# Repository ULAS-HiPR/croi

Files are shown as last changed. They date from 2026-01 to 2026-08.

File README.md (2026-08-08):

# Croí

Croí is the core flight-computer node in [Ogma](https://sean-osullivan.com/projects/ogma/), the University of Limerick Aeronautics Society's modular avionics stack for high-powered rocketry.

## Role

- Coordinates flight state across the 500 kbit/s CAN bus.
- Samples an LSM6DSO32 IMU and MS5607 barometer.
- Records flight data to SPI NOR flash.
- Runs on an STM32F072 and can operate as the stack's central logger.

## Repository

- `hardware/` - KiCad design and manufacturing outputs.
- `firmware/` - embedded firmware, peripheral probes, and tests.
- `schematics.png` - exported schematic overview.

## Status

Rev 1 firmware and hardware bring-up continue on [`ogma/flight-hardening`](https://github.com/ULAS-HiPR/croi/tree/ogma/flight-hardening). Release-candidate firmware builds and software tests pass, but hardware-in-the-loop validation is still underway. Croí is not yet flight-proven.

## Manufacturing support

Rev 1 PCB fabrication was sponsored through [EasyEDA Education](https://easyeda.com/education) and manufactured by [JLCPCB](https://jlcpcb.com/). The board was designed in KiCad and imported into EasyEDA Pro for the sponsorship and manufacturing workflow.

## More information

See the [Ogma project write-up](https://sean-osullivan.com/projects/ogma/) for the complete stack, bring-up work, and current status.

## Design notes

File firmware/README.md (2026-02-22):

# Croi

Heart of flight computer. It will run the Kalman filter and flight state machine. It is the core board to determine and send the trigger to the pyro board for  parachutes.

# Set-Up

```bash
git clone git@github.com:ULAS-HiPR/croi.git
cd croi
git submodule update --init --recursive
```

# Libraries used:

## From Braiteoiri:

- Flash: W25N01GV
- Baro: BMP390
- IMU:  LSM6DSO32
- Env: BME680
- LED
- Buzzer

## From Comheadan:

- CAN
- SPI
- I2C

## Other:
- FreeRTOS -> Cmsis wrapper, copied from gnereateed code from STM32CubeIDE
- Eigen

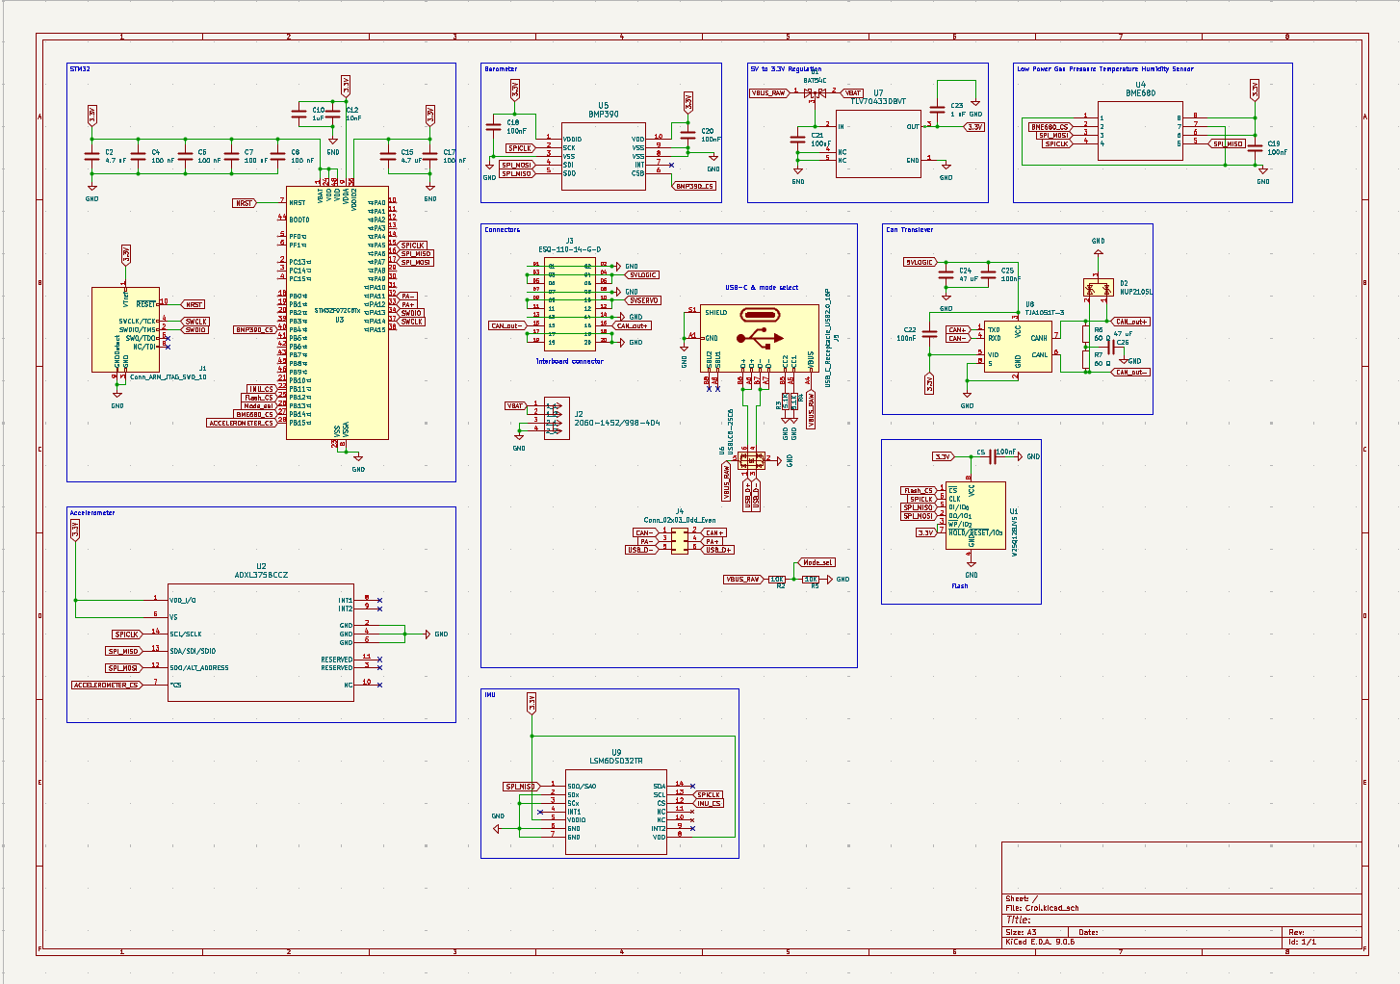
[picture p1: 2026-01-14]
schematics.png

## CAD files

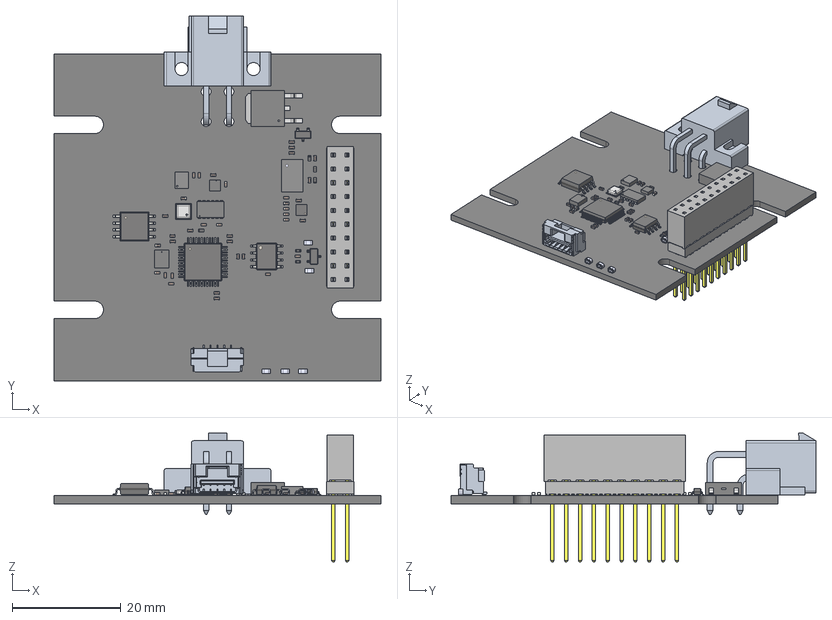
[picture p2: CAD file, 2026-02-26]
hardware/Croí - Kicad/Croí.step
60.0 x 66.9 x 23.6 mm
C_0402_1005Metric x 36
LGA_CC-14-1_ADI
PG-TO252-3-313_INF
R_0402_1005Metric x 6
S2761-46R x 5
XTAL_NX3225GD-8MHZ-STD-CRA-3_NDK
10LGA_2X2X0p75_BOS
SOIC-8_3.9x4.9mm_P1.27mm
SOIC-8_5.3x5.3mm_P1.27mm
ESQ-110-14-G-D-LL_socket
ESQ-110-14-G-D-LL_pins
ESQ-110-14-G-D-LL2_pins
ESQ-110-14-G-D-LL_bpins
LQFP-48_7x7mm_P0.5mm
MPM3650CGQW
LSM6DSO32TR 3D Model STEP
SOT-23 x 2
BME680 3D Model STEP 510211
WSON-6-1EP_2x2mm_P0.65mm_EP1x1.6mm
CroÃ_PCB

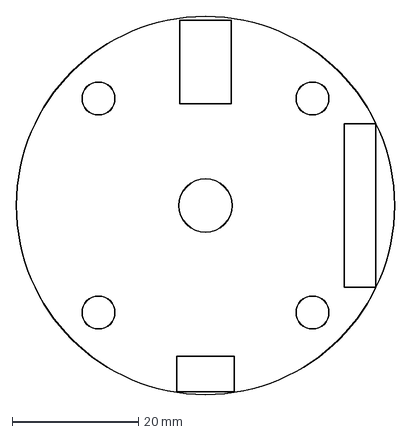
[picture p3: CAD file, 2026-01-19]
hardware/standardFootprint.dxf
60.0 x 60.0 mm

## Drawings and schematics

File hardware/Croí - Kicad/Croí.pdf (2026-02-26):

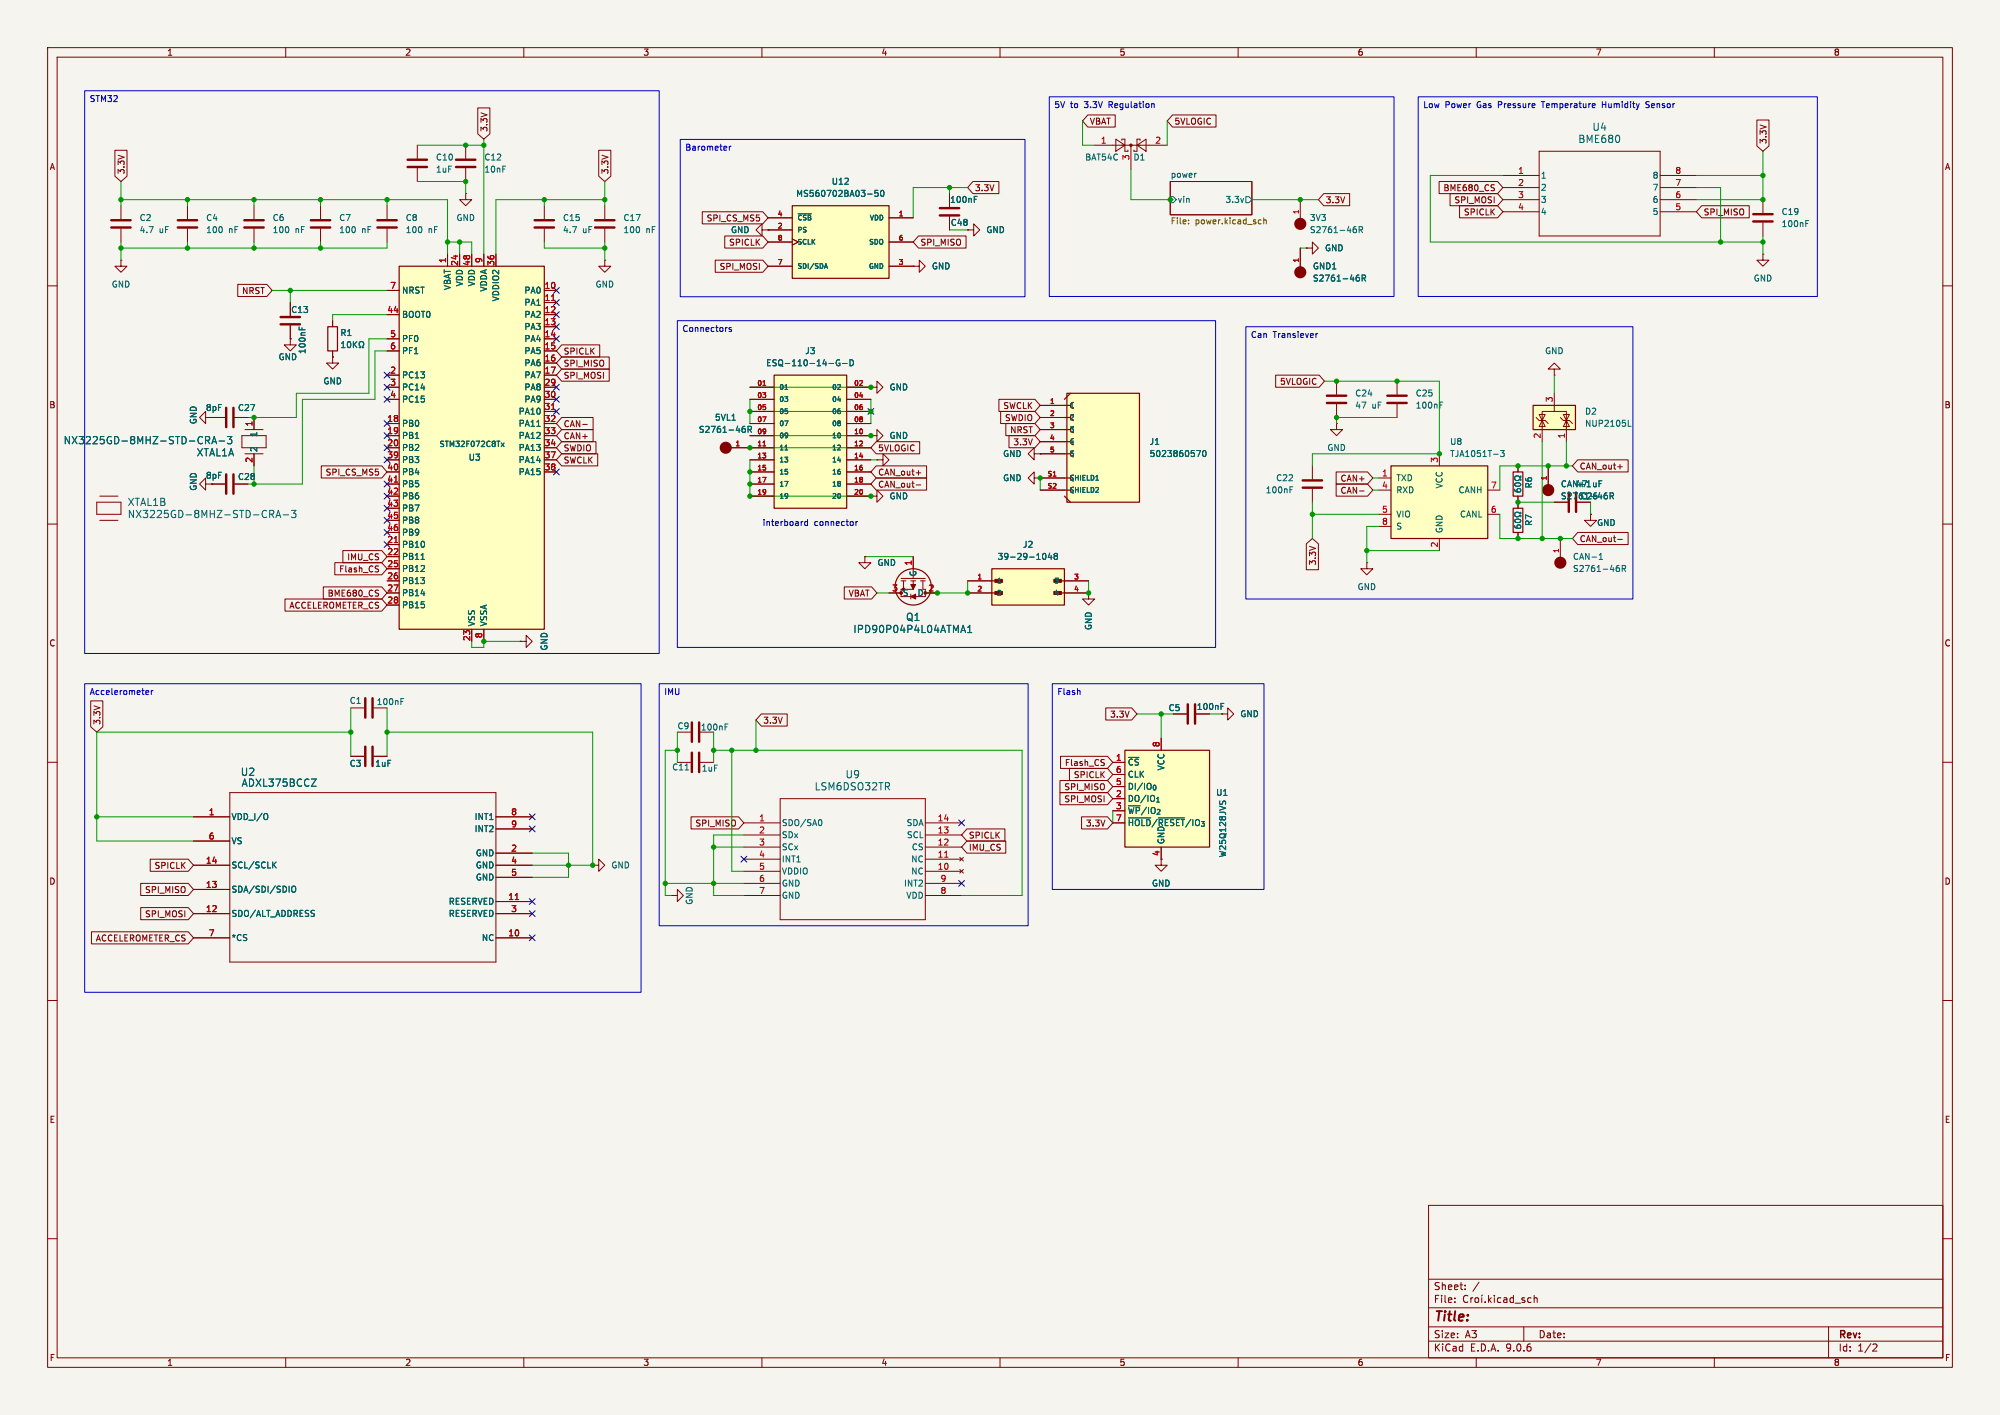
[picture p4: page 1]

1 VDD 24 VDD 48 VSS 23 VDDA

4 U1W25Q128JVS C5 100nF GND GND GND GND

Id: 1/2 Title: File: þÿCroí.kicad_sch Sheet: /

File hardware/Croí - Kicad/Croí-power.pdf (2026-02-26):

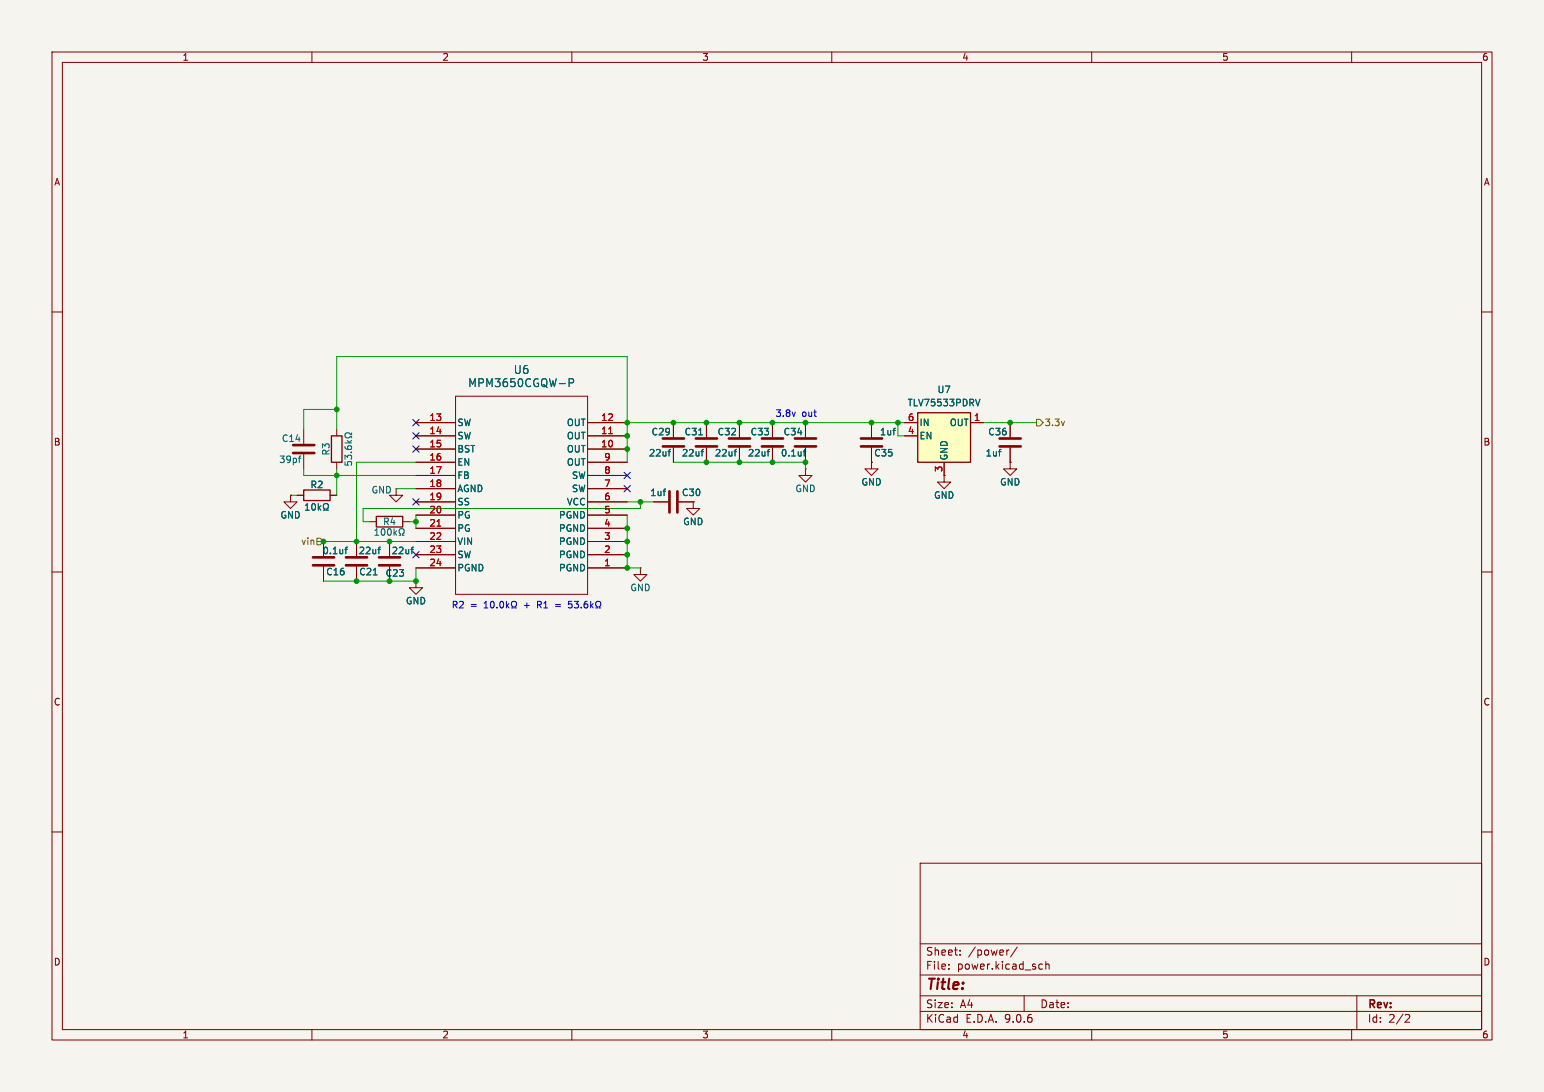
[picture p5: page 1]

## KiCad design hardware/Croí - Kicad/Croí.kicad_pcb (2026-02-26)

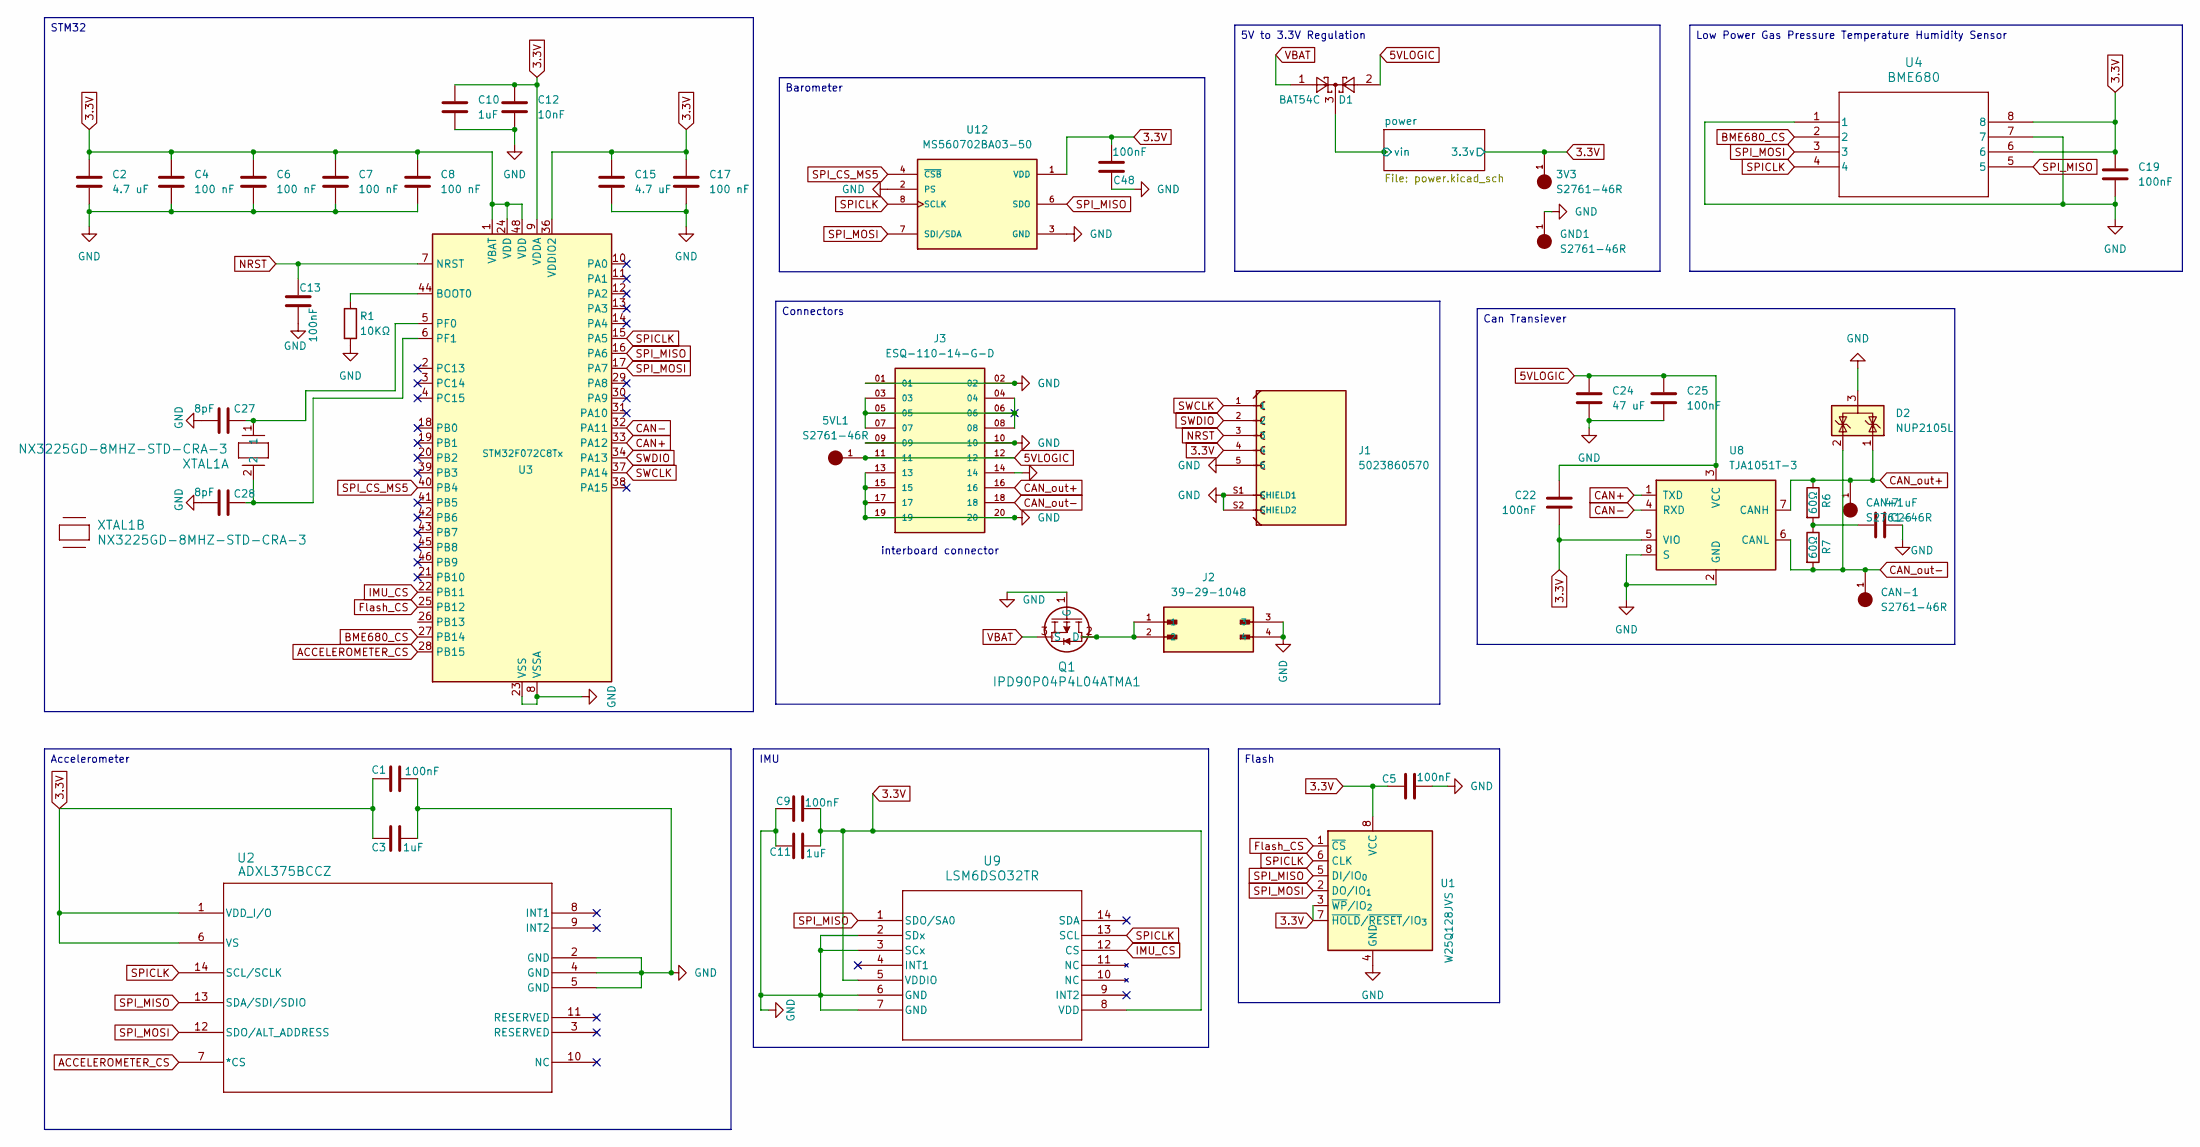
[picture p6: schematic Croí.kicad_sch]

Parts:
3V3, 5VL1: S2761-46R; HARWIN_S2761-46R; PARTREV 1
C1, C5, C9, C13, C19, C22, C25: 100nF; C_0402_1005Metric
C2, C15: 4.7 uF; C_0402_1005Metric
C3, C10, C11: 1uF; C_0402_1005Metric
C4, C6, C7, C8, C17: 100 nF; C_0402_1005Metric
C12: 10nF; C_0402_1005Metric
C24, C26: 47 uF; C_0402_1005Metric
C27, C28: 8pF; C_0402_1005Metric
C48: 100nF; R_0402_1005Metric
CAN+1: S2761-46R; HARWIN_S2761-46R; PARTREV 1
CAN-1: S2761-46R; HARWIN_S2761-46R; PARTREV 1
D1: BAT54C; SOT-23
D2: NUP2105L; SOT-23
GND1: S2761-46R; HARWIN_S2761-46R; PARTREV 1
J1: 5023860570; MOLEX_5023860570; PARTREV F
J2: 39-29-1048; MOLEX_39-29-1048
J3: ESQ-110-14-G-D; SAMTEC_ESQ-110-14-G-D; PARTREV NA
Q1: IPD90P04P4L04ATMA1; PG-TO252-3-313_INF
R1: 10KΩ; R_0402_1005Metric
R6, R7: 60Ω; R_0402_1005Metric
U1: W25Q128JVS; SOIC-8_5.3x5.3mm_P1.27mm
U2: ADXL375BCCZ; LGA_CC-14-1_ADI
U3: STM32F072C8Tx; LQFP-48_7x7mm_P0.5mm
U4: BME680; LGA8_BME680_BOS
U8: TJA1051T-3; SOIC-8_3.9x4.9mm_P1.27mm
U9: LSM6DSO32TR; LGA-14L_2P5X3X0P83_STM
U12: MS560702BA03-50; SON125P300X500X100-8N
XTAL1: NX3225GD-8MHZ-STD-CRA-3; XTAL_NX3225GD-8MHZ-STD-CRA-3_NDK

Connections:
3.3V: 3V3.1, C1.1, C2.1, C3.1, C4.1, C5.1, C6.1, C7.1, C8.1, C9.2, C10.1, C11.2, C12.1, C15.1, C17.1, C19.1, C22.1, C48.2, J1.4, U1.3 (~WP/IO_{2}), U1.7 (~HOLD/~RESET/IO_{3}), U1.8 (VCC), U2.1 (VDD_I/O), U2.6 (VS), U3.1 (VBAT), U3.9 (VDDA), U3.24 (VDD), U3.36 (VDDIO2), U3.48 (VDD), U4.6, U4.8, U8.5 (VIO), U9.5 (VDDIO), U9.8 (VDD), U12.1 (VDD); also elsewhere on the board
5VLOGIC: 5VL1.1, C22.2, C24.1, C25.1, D1.2, J3.11, J3.12, U8.3 (VCC)
/power/vin: D1.3; also elsewhere on the board
ACCELEROMETER_CS: U2.7 (*CS), U3.28 (PB15)
BME680_CS: U3.27 (PB14), U4.2
CAN+: U3.33 (PA12), U8.1 (TXD)
CAN-: U3.32 (PA11), U8.4 (RXD)
CAN_out+: CAN+1.1, D2.1 (K), J3.16, R6.1, U8.7 (CANH)
CAN_out-: CAN-1.1, D2.2 (K), J3.18, R7.2, U8.6 (CANL)
Flash_CS: U1.1 (~CS), U3.25 (PB12)
GND: C1.2, C2.2, C3.2, C4.2, C5.2, C6.2, C7.2, C8.2, C9.1, C10.2, C11.1, C12.2, C13.2, C15.2, C17.2, C19.2, C24.2, C25.2, C26.2, C27.1, C28.2, C48.1, D2.3 (A), GND1.1, J1.5, J1.S1 (SHIELD1), J1.S2 (SHIELD2), J2.3, J2.4, J3.01, J3.02, J3.09, J3.10, J3.13, J3.14, J3.15, J3.17, J3.19, J3.20, Q1.1 (G), R1.2, U1.4 (GND), U2.2 (GND), U2.4 (GND), U2.5 (GND), U3.8 (VSSA), U3.23 (VSS), U3.35 (VSS), U3.47 (VSS), U4.1, U4.7, U8.2 (GND), U8.8 (S), U9.2 (SDx), U9.3 (SCx), U9.6 (GND), U9.7 (GND), U12.2 (PS), U12.3 (GND); also elsewhere on the board
IMU_CS: U3.22 (PB11), U9.12 (CS)
NRST: C13.1, J1.3, U3.7 (NRST)
unnamed: C26.1, R6.2, R7.1
unnamed: J2.1, J2.2, Q1.2 (D)
unnamed: R1.1, U3.44 (BOOT0)
unnamed: C27.2, U3.5 (PF0), XTAL1.1
unnamed: C28.1, U3.6 (PF1), XTAL1.2
SPICLK: U1.6 (CLK), U2.14 (SCL/SCLK), U3.15 (PA5), U4.4, U9.13 (SCL), U12.8 (SCLK)
SPI_CS_MS5: U3.40 (PB4), U12.4 (~CSB), U12.5 (~CSB)
SPI_MISO: U1.5 (DI/IO_{0}), U2.13 (SDA/SDI/SDIO), U3.16 (PA6), U4.5, U9.1 (SDO/SA0), U12.6 (SDO)
SPI_MOSI: U1.2 (DO/IO_{1}), U2.12 (SDO/ALT_ADDRESS), U3.17 (PA7), U4.3, U12.7 (SDI/SDA)
SWCLK: J1.1, U3.37 (PA14)
SWDIO: J1.2, U3.34 (PA13)
VBAT: D1.1, Q1.3 (S)

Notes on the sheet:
interboard connector
Low Power Gas Pressure Temperature Humidity Sensor
Can Transiever
Barometer
Flash
5V to 3.3V Regulation
Accelerometer
IMU
STM32
Connectors

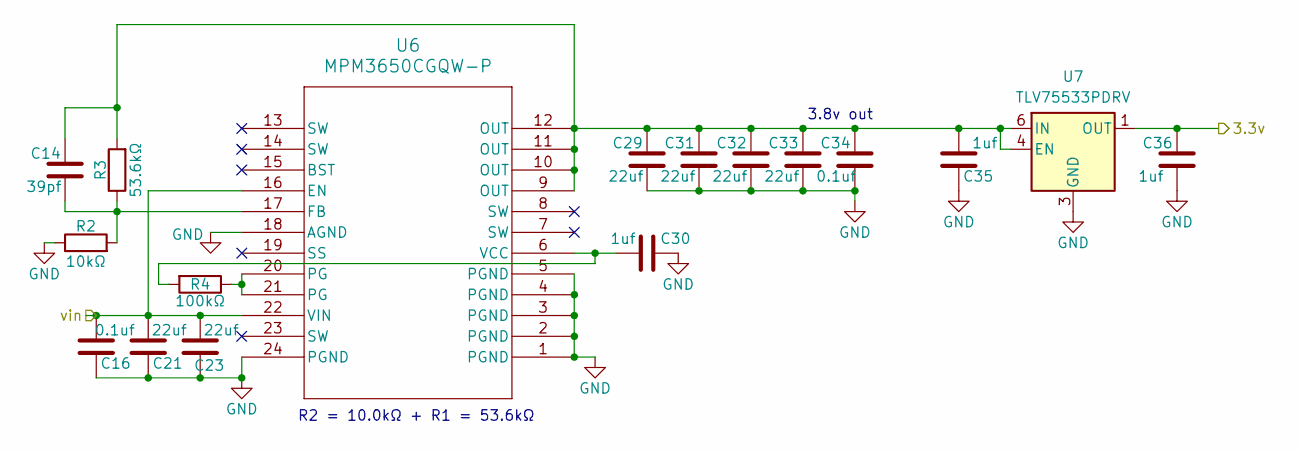
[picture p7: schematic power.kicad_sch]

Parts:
C14: 39pf; C_0402_1005Metric
C16, C34: 0.1uf; C_0402_1005Metric
C21, C23, C29, C31, C32, C33: 22uf; C_0402_1005Metric
C30, C35, C36: 1uf; C_0402_1005Metric
R2: 10kΩ; R_0402_1005Metric
R3: 53.6kΩ; R_0402_1005Metric
R4: 100kΩ; R_0402_1005Metric
U6: MPM3650CGQW-P; QFN-24_MPM3650_MNP
U7: TLV75533PDRV; WSON-6-1EP_2x2mm_P0.65mm_EP1x1.6mm

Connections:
3.3V: C36.1, U7.1 (OUT); also elsewhere on the board
/power/vin: C16.2, C21.2, C23.2, U6.16 (EN), U6.22 (VIN); also elsewhere on the board
GND: C16.1, C21.1, C23.1, C29.2, C30.1, C31.2, C32.2, C33.2, C34.2, C35.1, C36.2, R2.1, U6.1 (PGND), U6.2 (PGND), U6.3 (PGND), U6.4 (PGND), U6.5 (PGND), U6.18 (AGND), U6.24 (PGND), U7.3 (GND), U7.7 (GND); also elsewhere on the board
unnamed: R4.1, U6.20 (PG), U6.21 (PG)
unnamed: C14.2, R2.2, R3.1, U6.17 (FB)
unnamed: C30.2, R4.2, U6.6 (VCC)
unnamed: C14.1, C29.1, C31.1, C32.1, C33.1, C34.1, C35.2, R3.2, U6.9 (OUT), U6.10 (OUT), U6.11 (OUT), U6.12 (OUT), U7.4 (EN), U7.6 (IN)

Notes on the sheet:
3.8v out
R2 = 10.0kΩ + R1 = 53.6kΩ

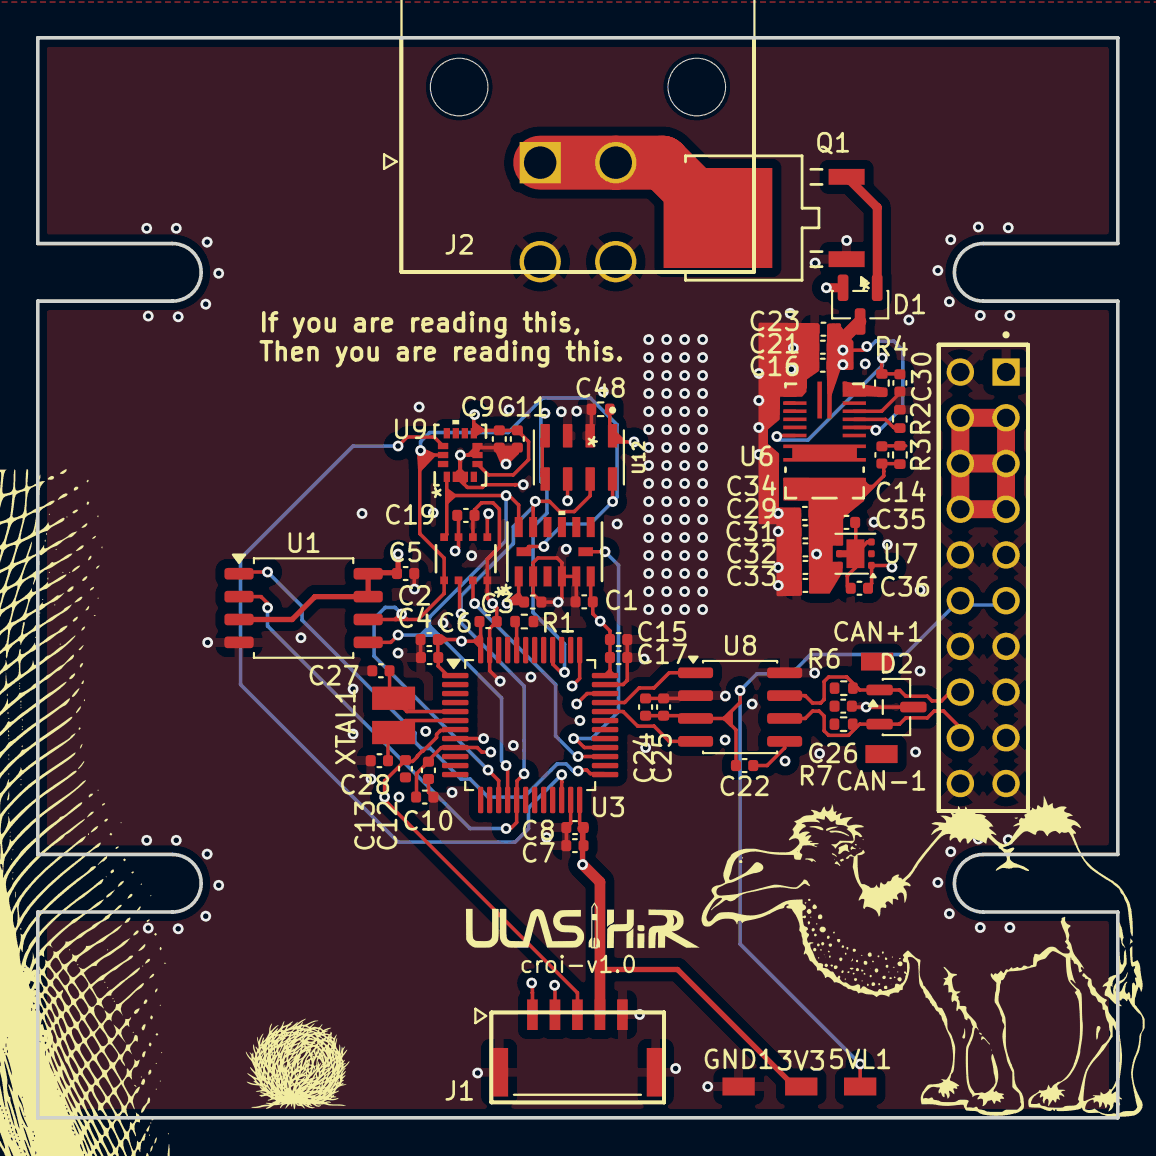
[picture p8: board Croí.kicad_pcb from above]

Board: 6 copper layers, 60.0 x 60.0 mm, 62 parts (0 on the bottom side), 29 nets.

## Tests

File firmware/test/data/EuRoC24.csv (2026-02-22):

ts | height | velocity | acceleration
-0.75 | 0.4530242681503296 | 0.1455255150794983 | -0.02075336128473282
-0.74 | 0.4542248249053955 | 0.14505557715892792 | -0.02075744792819023
-0.73 | 0.45539671182632446 | 0.14465756714344025 | -0.011028729379177094
-0.72 | 0.45654067397117615 | 0.1442347764968872 | -0.011033594608306885
-0.71 | 0.4576570689678192 | 0.14378778636455536 | -0.01103883609175682
-0.7 | 0.4587462246417999 | 0.14331720769405365 | -0.011044444516301155
-0.69 | 0.45980846881866455 | 0.14282359182834625 | -0.011050410568714142
-0.68 | 0.46245095133781433 | 0.1439698040485382 | -0.011030841618776321
-0.67 | 0.46505051851272583 | 0.1450599730014801 | -0.01101214811205864
-0.66 | 0.4676075279712677 | 0.14609502255916595 | -0.010994315147399902
-0.65 | 0.4701223075389862 | 0.1470758467912674 | -0.010977329686284065
-0.64 | 0.4813291132450104 | 0.1572326123714447 | 0.008643997833132744
-0.63 | 0.497358500957489 | 0.17246860265731812 | 0.02834136039018631
-0.62 | 0.5132084488868713 | 0.1872667670249939 | 0.01883569173514843
-0.61 | 0.5252976417541504 | 0.19802352786064148 | 0.019000258296728134
-0.6 | 0.5372442007064819 | 0.20842623710632324 | 0.009429508820176125
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

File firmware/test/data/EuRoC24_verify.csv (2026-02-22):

ts | state
0 | 3
5.69 | 4
21.22 | 5
110.36 | 6
122.12 | 7

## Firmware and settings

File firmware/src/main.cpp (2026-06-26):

#include "data.h"
#include <cstdint>
#if F4
#include "stm32f4xx_hal.h"
#include "platform/stm_f4.h"
#endif
#if F0
#include "stm32f0xx_hal.h"
#include "platform/stm_f0.h"
#endif
#include "platform/error_handler.h"
#include "cmsis_os.h"
#include <data.h>

#include "tasks/state_machine.h"
#include "tasks/CAN_task.h"
#include "tasks/logger.h"

//Generic henders
#include <sensor.h>
#include <IMU/IMU.h>
#include <Baro/baro.h>
#include <Flash/flash.h>
#include <Buzzer/buzzer.h>
#include <SPI/SPI_STM.h>
#include <CAN/CAN_Handler.h>
#if F4
#include <CAN/CAN_Mock.h>
#elif F0
#include <CAN/CAN_STM.h>
#endif

//Specific sensors
#include <IMU/LSM6DSO32.h>
#include <Baro/MS5607.h>
#include <Flash/MX25L128.h>
#include <Buzzer/buzzer_stm.h>
//#inlcude <IMU/ADXL347.h>
//#include <Env/BME280.h>


void SystemClock_Config(void);
void Error_Handler(void);

const osMessageQueueAttr_t canRQueue_attributes = {
  .name = "canReciverQueue"
};

const osMessageQueueAttr_t canSQueue_attributes = {
  .name = "canSenderQueue"
};

const osMessageQueueAttr_t loggingQueue_attributes = {
  .name = "loggingQueue"
};


int main(void)
  {
    HAL_Init();
    SystemClock_Config();
    
    MX_GPIO_Init();
    MX_SPI1_Init();
    MX_TIM3_Init();
    osKernelInitialize();

    SPI_Handler* spi_handler_baro = new SPI_STM(&hspi1, BARO_CS_PORT, BARO_CS_PIN);
    SPI_Handler* spi_handler_imu = new SPI_STM(&hspi1, IMU_CS_PORT, IMU_CS_PIN);
    //SPI_Handler* spi_handler_flash = new SPI_STM(&hspi1, FLASH_CS_PORT, FLASH_CS_PIN);

    bool init_status = true;
    //Flash* flash_memory = new MX25L128(*spi_handler_flash);
    //init_status &= flash_memory->init();
    
    IMU* imu = new LSM6DSO32(*spi_handler_imu);
    Baro* baro = new MS5607(*spi_handler_baro);
    Buzzer* buzzer = new Buzzer_STM(&htim3, TIM_CHANNEL_3);

    buzzer->init();
    buzzer->play_startup();


    init_status &= imu->init();
    init_status &= baro->init();

    //fake memory location
    uint8_t buffer[sizeof(flash_internal_data)];
    //bool read_correctly = flash_memory->read(0x00, &buffer[0], sizeof(flash_internal_data));
    //flash_internal_data* settings = reinterpret_cast<flash_internal_data*>(buffer);
    // test settings
    flash_internal_data* settings = new flash_internal_data{
        .main_height = 200,
        .drouge_delay = 0,
        .liftoff_thresh = 20
    };

    #if F4
      CAN_Handler* canbus = new CAN_MOCK();
    #elif F0
      MX_CAN_Init();
      CAN_Handler* canbus = new CAN_STM(&hcan);
      bool can_init_status = canbus->init();
    #endif
  
    osMessageQueueId_t canReciverQueueHandle = osMessageQueueNew(4, sizeof(flight_data), &canRQueue_attributes);
    osMessageQueueId_t canSenderQueueHandle = osMessageQueueNew(4, sizeof(flight_data), &canSQueue_attributes);
    osMessageQueueId_t loggingQueueHandle = osMessageQueueNew(4, sizeof(flight_data), &loggingQueue_attributes);

    static task::StateMachine state_machine(imu, baro, settings, canSenderQueueHandle, loggingQueueHandle);
    static task::CAN_task can_task(*canbus, canSenderQueueHandle, canReciverQueueHandle);
    //static task::Logger logger(flash_memory, loggingQueueHandle, canReciverQueueHandle);

    //can_task.run();
    state_machine.run();
    //logger.run();
    //size_t freeHeap = xPortGetFreeHeapSize();
    //printf("Free heap size: %u bytes\n", freeHeap);

    osKernelStart();
    // never get here 
    while (1)
    {
      HAL_Delay(1000);
    }
    }



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


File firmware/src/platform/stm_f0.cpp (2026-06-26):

#if F0
#include "stm_f0.h"


CAN_HandleTypeDef hcan;
SPI_HandleTypeDef hspi1;
TIM_HandleTypeDef htim3;

void HAL_MspInit(void)
{

  __HAL_RCC_SYSCFG_CLK_ENABLE();
  __HAL_RCC_PWR_CLK_ENABLE();

  /* System interrupt init*/
  /* PendSV_IRQn interrupt configuration */
  HAL_NVIC_SetPriority(PendSV_IRQn, 3, 0);

}



/**
  * @brief CAN Initialization Function
  * @param None
  * @retval None
  */
void MX_CAN_Init(void)
{

  hcan.Instance = CAN;
  hcan.Init.Prescaler = 6;
  //hcan.Init.Mode = CAN_MODE_LOOPBACK;
  hcan.Init.Mode = CAN_MODE_NORMAL;
  hcan.Init.SyncJumpWidth = CAN_SJW_1TQ;
  hcan.Init.TimeSeg1 = CAN_BS1_13TQ;
  hcan.Init.TimeSeg2 = CAN_BS2_2TQ;
  hcan.Init.TimeTriggeredMode = DISABLE;
  hcan.Init.AutoBusOff = DISABLE;
  hcan.Init.AutoWakeUp = DISABLE;
  hcan.Init.AutoRetransmission = ENABLE;
  hcan.Init.ReceiveFifoLocked = DISABLE;
  hcan.Init.TransmitFifoPriority = DISABLE;
  if (HAL_CAN_Init(&hcan) != HAL_OK)
  {
    Error_Handler();
  }
}


/**
  * @brief CAN MSP Initialization
  * This function configures the hardware resources used in this example
  * @param hcan: CAN handle pointer
  * @retval None
  */
void HAL_CAN_MspInit(CAN_HandleTypeDef* hcan)
{
  GPIO_InitTypeDef GPIO_InitStruct = {0};
  if(hcan->Instance==CAN)
  {
    /* Peripheral clock enable */
    __HAL_RCC_CAN1_CLK_ENABLE();

    __HAL_RCC_GPIOA_CLK_ENABLE();
    /**CAN GPIO Configuration
    PA11     ------> CAN_RX
    PA12     ------> CAN_TX
    */
    GPIO_InitStruct.Pin = GPIO_PIN_11|GPIO_PIN_12;
    GPIO_InitStruct.Mode = GPIO_MODE_AF_PP;
    GPIO_InitStruct.Pull = GPIO_NOPULL;
    GPIO_InitStruct.Speed = GPIO_SPEED_FREQ_HIGH;
    GPIO_InitStruct.Alternate = GPIO_AF4_CAN;
    HAL_GPIO_Init(GPIOA, &GPIO_InitStruct);

  }

}

/**
  * @brief CAN MSP De-Initialization
  * This function freeze the hardware resources used in this example
  * @param hcan: CAN handle pointer
  * @retval None
  */
void HAL_CAN_MspDeInit(CAN_HandleTypeDef* hcan)
{
  if(hcan->Instance==CAN)
  {
    /* Peripheral clock disable */
    __HAL_RCC_CAN1_CLK_DISABLE();

    /**CAN GPIO Configuration
    PA11     ------> CAN_RX
    PA12     ------> CAN_TX
    */
    HAL_GPIO_DeInit(GPIOA, GPIO_PIN_11|GPIO_PIN_12);

  }

}

void MX_SPI1_Init(void)
{

  /* SPI1 parameter configuration*/
  hspi1.Instance = SPI1;
  hspi1.Init.Mode = SPI_MODE_MASTER;
  hspi1.Init.Direction = SPI_DIRECTION_2LINES;
  hspi1.Init.DataSize = SPI_DATASIZE_8BIT;
  hspi1.Init.CLKPolarity = SPI_POLARITY_LOW;
  hspi1.Init.CLKPhase = SPI_PHASE_1EDGE;
  hspi1.Init.NSS = SPI_NSS_SOFT;
  hspi1.Init.BaudRatePrescaler = SPI_BAUDRATEPRESCALER_8;
  hspi1.Init.FirstBit = SPI_FIRSTBIT_MSB;
  hspi1.Init.TIMode = SPI_TIMODE_DISABLE;
  hspi1.Init.CRCCalculation = SPI_CRCCALCULATION_DISABLE;

  if (HAL_SPI_Init(&hspi1) != HAL_OK)
  {
    Error_Handler();
  }
}


void HAL_SPI_MspInit(SPI_HandleTypeDef* hspi)
{
    if (hspi->Instance != SPI1) {
        return;
    }

    SPI_GPIO_CLK_ENABLE();
    FLASH_CS_GPIO_CLK_ENABLE();
    __HAL_RCC_SPI1_CLK_ENABLE();

    GPIO_InitTypeDef GPIO_InitStruct = {0};
    GPIO_InitStruct.Pin = SPI_SCK_PIN | SPI_MISO_PIN | SPI_MOSI_PIN;
    GPIO_InitStruct.Mode = GPIO_MODE_AF_PP;
    GPIO_InitStruct.Pull = GPIO_NOPULL;
    GPIO_InitStruct.Speed = GPIO_SPEED_FREQ_HIGH;
    GPIO_InitStruct.Alternate = GPIO_AF0_SPI1;
    HAL_GPIO_Init(SPI_GPIO_PORT, &GPIO_InitStruct);

    GPIO_InitStruct.Pin = BARO_CS_PIN |
                           IMU_CS_PIN |
                           FLASH_CS_PIN |
                           BME680_CS_PIN |
                           ADXL375_CS_PIN;
    GPIO_InitStruct.Mode = GPIO_MODE_OUTPUT_PP;
    GPIO_InitStruct.Pull = GPIO_NOPULL;
    GPIO_InitStruct.Speed = GPIO_SPEED_FREQ_HIGH;
    HAL_GPIO_Init(GPIOB, &GPIO_InitStruct);
    HAL_GPIO_WritePin(BARO_CS_PORT, BARO_CS_PIN, GPIO_PIN_SET);
    HAL_GPIO_WritePin(IMU_CS_PORT, IMU_CS_PIN, GPIO_PIN_SET);
    HAL_GPIO_WritePin(FLASH_CS_PORT, FLASH_CS_PIN, GPIO_PIN_SET);
    HAL_GPIO_WritePin(BME680_CS_PORT, BME680_CS_PIN, GPIO_PIN_SET);
    HAL_GPIO_WritePin(ADXL375_CS_PORT, ADXL375_CS_PIN, GPIO_PIN_SET);
}

/**
  * @brief SPI MSP De-Initialization
  * This function freeze the hardware resources used in this example
  * @param hspi: SPI handle pointer
  * @retval None
  */
void HAL_SPI_MspDeInit(SPI_HandleTypeDef* hspi)
{
  if(hspi->Instance==SPI1)
  {
    /* Peripheral clock disable */
    __HAL_RCC_SPI1_CLK_DISABLE();

    /**SPI1 GPIO Configuration
    PA5     ------> SPI1_SCK
    PA6     ------> SPI1_MISO
    PA7     ------> SPI1_MOSI
    */
    HAL_GPIO_DeInit(GPIOA, GPIO_PIN_5|GPIO_PIN_6|GPIO_PIN_7 | BARO_CS_PIN | IMU_CS_PIN | FLASH_CS_PIN | BME680_CS_PIN | ADXL375_CS_PIN);

  }

}

/**
  * @brief GPIO Initialization Function
  * @param None
  * @retval None
  */
void MX_GPIO_Init(void)
{
  GPIO_InitTypeDef GPIO_InitStruct = {0};
  /* GPIO Ports Clock Enable */
  __HAL_RCC_GPIOA_CLK_ENABLE();
  __HAL_RCC_GPIOB_CLK_ENABLE();

  /*Configure GPIO pin Output Level */
  //HAL_GPIO_WritePin(GPIOB, GPIO_PIN_0| GPIO_PIN_RESET);

  /*Configure GPIO pins : PB0 IMU_CS_Pin FLASH_CS_Pin BME_CS_Pin
                           ADXL_CS_Pin BARO_CS_Pin */
  GPIO_InitStruct.Pin = GPIO_PIN_0;
  GPIO_InitStruct.Mode = GPIO_MODE_OUTPUT_PP;
  GPIO_InitStruct.Pull = GPIO_NOPULL;
  GPIO_InitStruct.Speed = GPIO_SPEED_FREQ_LOW;
  HAL_GPIO_Init(GPIOB, &GPIO_InitStruct);

}

void HAL_TIM_PWM_MspInit(TIM_HandleTypeDef* htim)
{
    if (htim->Instance == TIM3) {
        __HAL_RCC_TIM3_CLK_ENABLE();
    }
}

void HAL_TIM_MspPostInit(TIM_HandleTypeDef* htim)
{
    if (htim->Instance != TIM3) {
        return;
    }

    __HAL_RCC_GPIOB_CLK_ENABLE();

    GPIO_InitTypeDef gpio = {0};
    gpio.Pin = BUZZER_GPIO_PIN;
    gpio.Mode = GPIO_MODE_AF_PP;
    gpio.Pull = GPIO_NOPULL;
    gpio.Speed = GPIO_SPEED_FREQ_HIGH;
    gpio.Alternate = GPIO_AF1_TIM3;
    HAL_GPIO_Init(BUZZER_GPIO_PORT, &gpio);
}



void MX_TIM3_Init(void)
{
    TIM_OC_InitTypeDef config = {0};

    uint32_t timer_clock = HAL_RCC_GetPCLK1Freq();
    uint32_t prescaler = timer_clock / BUZZER_TIMER_TICK_HZ;
    if (prescaler == 0U) {
        prescaler = 1U;
    }

    htim3.Instance = TIM3;
    htim3.Init.Prescaler = prescaler - 1U;
    htim3.Init.CounterMode = TIM_COUNTERMODE_UP;
    htim3.Init.Period = 1000U - 1U;
    htim3.Init.ClockDivision = TIM_CLOCKDIVISION_DIV1;
    htim3.Init.AutoReloadPreload = TIM_AUTORELOAD_PRELOAD_DISABLE;

    if (HAL_TIM_PWM_Init(&htim3) != HAL_OK) {
        Error_Handler();
    }

    config.OCMode = TIM_OCMODE_PWM1;
    config.Pulse = 0;
    config.OCPolarity = TIM_OCPOLARITY_HIGH;
    config.OCFastMode = TIM_OCFAST_DISABLE;

    if (HAL_TIM_PWM_ConfigChannel(&htim3, &config, TIM_CHANNEL_3) != HAL_OK) {
        Error_Handler();
    }

    HAL_TIM_MspPostInit(&htim3);

    if (HAL_TIM_PWM_Start(&htim3, TIM_CHANNEL_3) != HAL_OK) {
        Error_Handler();
    }

    if (htim3.Instance != nullptr) {
        __HAL_TIM_SET_COMPARE(&htim3, TIM_CHANNEL_3, 0);
    }
}

#endif // F0

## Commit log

2026-01-14 First addition of Kicad project
    [Croí.kicad_pcb, Croí.kicad_sch]
2026-01-14 minor junctions
    [Croí.kicad_sch]
2026-01-14 did basically all of it
    [Croí.kicad_pcb, Croí.kicad_sch]
2026-01-14 started pcb work
    [Croí.kicad_pcb, Croí.kicad_sch]
2026-01-14 Finalised board with accelerometer and IMU
    [Croí.kicad_pcb, Croí.kicad_sch]
2026-01-19 summaries are hard
    [Croí.kicad_pcb, Croí.kicad_sch, standardFootprint.dxf]
2026-01-22 changed some stuff
    [Croí.kicad_pcb, Croí.kicad_sch]
2026-01-22 crazy work
    [Croí.kicad_pcb, Croí.kicad_sch]
2026-01-24 Board Routing completed: Ready for Review
    [Croí.kicad_pcb, Croí.kicad_sch]
2026-01-26 minor changes
    [Croí.kicad_pcb, Croí.kicad_sch]
2026-01-26 Memes added, Dervla might recognise someone
    [Croí.kicad_pcb]
2026-01-27 major changes
    [Croí.kicad_pcb]
2026-01-27 repositioned board
    [Croí.kicad_pcb]
2026-01-28 random ass changes
    [Croí.kicad_pcb, Croí.kicad_sch]
2026-01-29 Crazy new changes
    [Croí.kicad_pcb, Croí.kicad_sch]
2026-01-29 cleaning up: should be near done now
    [Croí.kicad_pcb]
2026-01-30 cleaned up
    [Croí.kicad_pcb, Croí.kicad_sch]
2026-01-31 cleaned up a trace
    [Croí.kicad_pcb]
2026-02-07 Started Applying Global Changes
    1. Shape and screwholes
    2. Mosfet
    3. New Molex
    [Croí.kicad_pcb, Croí.kicad_sch]
2026-02-10 Only missing one thing off the notion i believe, all 3d modlels should work
    [Croí.kicad_pcb, Croí.kicad_sch]
2026-02-11 lots left to do, but good enough for render
    [Croí.kicad_pcb, Croí.kicad_sch, power.kicad_sch]
2026-02-16 clean asf
    [Croí.kicad_pcb, Croí.kicad_sch]
2026-02-22 adding base software for an example, not working, fightin with eigen
    [kalman_filter.h, main.cpp]
2026-02-22 most issues solved, the thing i knew would cause issues not causing issues:
    [kalman_filter.h, main.cpp]
2026-02-22 fuck the compiler i hate this
    [EuRoC24.csv, EuRoC24_verify.csv]
2026-02-23 Removing fake static analysis errors
    [main.cpp]
2026-02-23 ready for review the twost
    [Croí.kicad_pcb, Croí.step]
2026-02-26 good to go
    [Croí.kicad_pcb, Croí.kicad_sch]
2026-04-21 re ing fake static analysis errors
    [main.cpp]
2026-04-21 adding common tasks & importing correct sensors
    [main.cpp]
2026-04-21 fixed all build errors & added correct queues
    [main.cpp]
2026-05-27 fixed all compile errors
    [main.cpp, stm_f0.cpp, stm_f0.h]
2026-05-27 updated kalman to all floats & fixed memory issue
    [kalman_filter.h]
2026-06-10 fixing overall freeRTOS stuff - getting odd error
    [kalman_filter.h, main.cpp]
2026-06-22 fix: stripping back to isolate CAN
    [main.cpp, stm_f0.cpp, stm_f0.h]
2026-06-23 feat: buzzer, imu & baro working in loops
    [main.cpp, stm_f0.cpp, stm_f0.h]
